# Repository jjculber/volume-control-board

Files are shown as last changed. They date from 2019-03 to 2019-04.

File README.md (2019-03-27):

# volume-control-board

Volume? Level?

The goal of this project is to make a small PCB for controlling volume with a rotary encoder and digital potentiometer.

- __Audio Input__: 3.5mm TRS jack
- __Digital Potentiometer__: AD5254 (4 circuits, 256 taps, 10k or 50k ohms)
- __Audio Output__: Shielded RJ45 for sending 4 channels to amplifier with cat6

[schematic](hardware/schematic.pdf)

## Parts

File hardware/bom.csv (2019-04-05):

Id | Designator | Package | Quantity | Designation | Supplier and ref | Note
1 | J2 | Jack_3.5mm_CUI_SJ-3523-SMT_Horizontal | 1 | AudioJack3 | CP-3523SJCT-ND
2 | REF**,REF**,REF**,REF** | MountingHole_2.2mm_M2 | 4 | MountingHole_2.2mm_M2
3 | C1,C2,C3,C4,C5 | C_0805 | 5 | 0.1uF
4 | J1 | Socket_Strip_Straight_1x08_Pitch2.54mm | 1 | Screw_Terminal_01x08 | A98333-ND (x4)
5 | J4,J5 | Socket_Strip_Straight_1x04_Pitch2.54mm | 2 | Conn_01x04 | A98333-ND (x2)
6 | J6 | Socket_Strip_Straight_1x02_Pitch2.54mm | 1 | RXTX/CAN | A98333-ND
7 | JP1,JP2,JP3,JP4,JP5,JP6,JP7,JP8,JP9,JP10,JP11,JP12 | SolderJumper-2_P1.3mm_Open_RoundedPad1.0x1.5mm | 12 | SolderJumper_2_Open
8 | R1,R2 | R_0805 | 2 | 2.2k
9 | R3,R4,R5,R6,R7,R8,R9 | R_0805 | 7 | 10k
10 | R10,R11,R12,R13 | R_0805 | 4 | R
11 | SW1 | RotaryEncoder_Alps_EC11E-Switch_Vertical_H20mm | 1 | Rotary_Encoder_Switch | 987-1188-ND
12 | U1 | Teensy30_31_32_LC | 1 | Teensy3.2 | 1568-1231-ND
13 | U2 | TSSOP-20_4.4x6.5mm_Pitch0.65mm | 1 | AD5254 | AD5254BRUZ10-RL7CT-ND
14 | J7,J3 | Grove_1x04 | 2 | Conn_01x04 | 455-1706-ND | 6 inch jumper cable: 455-3151-ND

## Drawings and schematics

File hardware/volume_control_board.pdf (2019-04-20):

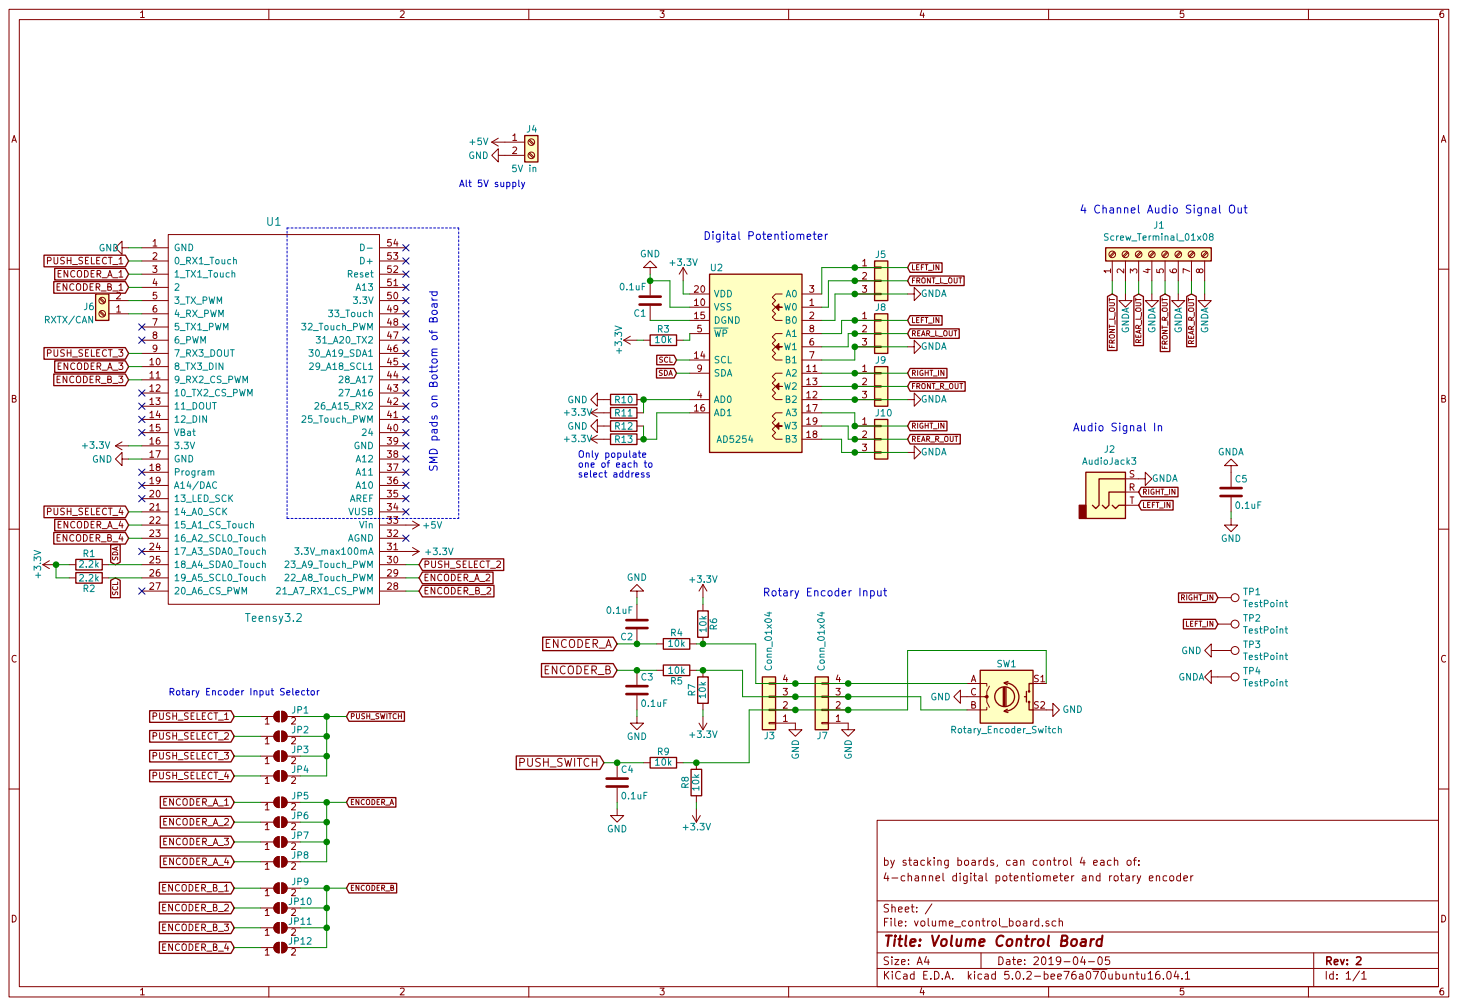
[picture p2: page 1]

SCL SDA

0.1uF GND Audio Signal In

one of each to

JP12 Rotary Encoder Input Selector

by stacking boards, can control 4 each of:
File: volume_control_board.sch Sheet: / 4-channel digital potentiometer and rotary encoder

Id: 1/1 Title: Volume Control Board

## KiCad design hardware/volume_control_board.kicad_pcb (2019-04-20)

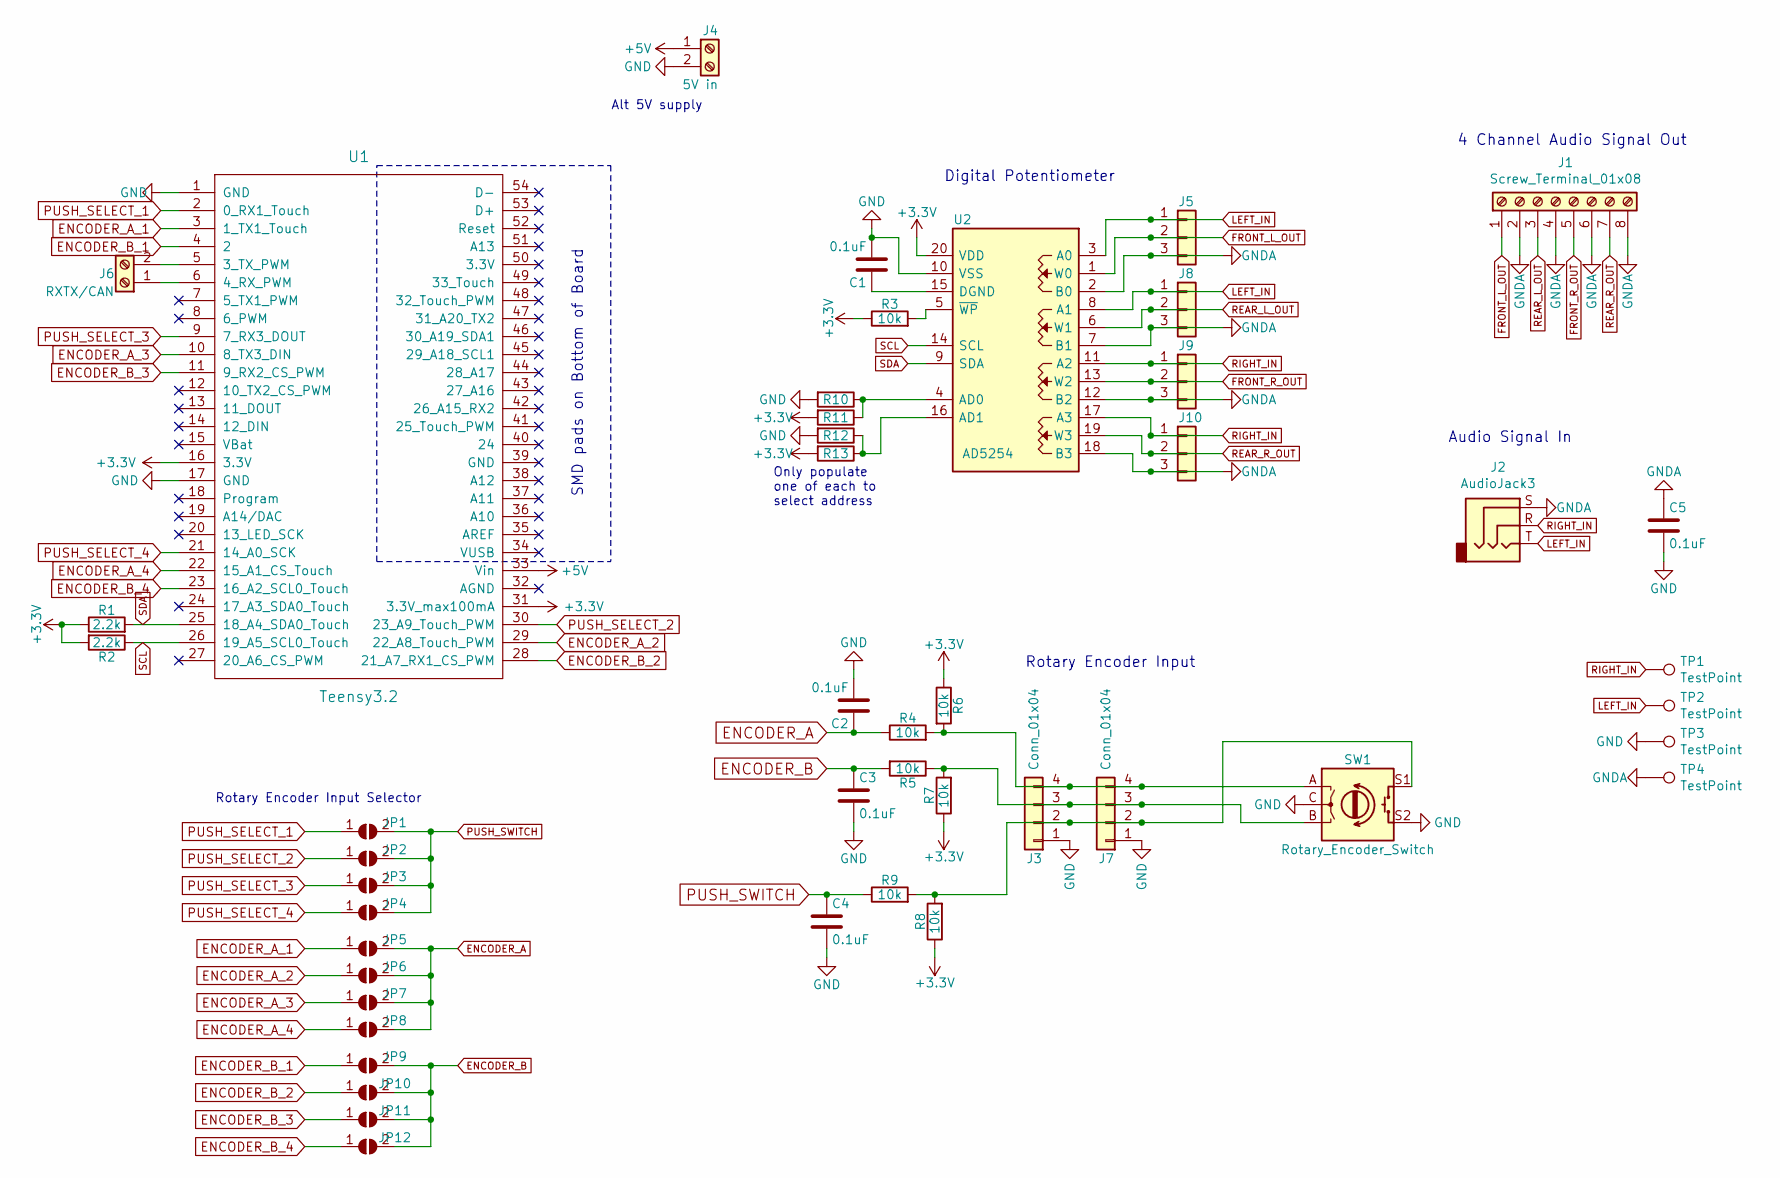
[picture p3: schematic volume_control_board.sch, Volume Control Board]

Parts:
C1, C2, C3, C4, C5: 0.1uF; C_0805
J1: Screw_Terminal_01x08; Socket_Strip_Straight_1x08_Pitch2.54mm
J2: AudioJack3; Jack_3.5mm_CUI_SJ-3523-SMT_Horizontal
J3, J7: Conn_01x04; Grove_1x04
J4: 5V in; Socket_Strip_Straight_1x02_Pitch2.54mm
J5, J8, J9, J10: Conn_01x03; Socket_Strip_Straight_1x03_Pitch2.00mm
J6: RXTX/CAN; Socket_Strip_Straight_1x02_Pitch2.54mm
JP1, JP2, JP3, JP4, JP5, JP6, JP7, JP8, JP9, JP10, JP11, JP12: SolderJumper_2_Open; SolderJumper-2_P1.3mm_Open_RoundedPad1.0x1.5mm
R1, R2: 2.2k; R_0805
R3, R4, R5, R6, R7, R8, R9: 10k; R_0805
R10, R11, R12, R13: R; R_0805
SW1: Rotary_Encoder_Switch; RotaryEncoder_Alps_EC11E-Switch_Vertical_H20mm
TP1, TP2, TP3, TP4: TestPoint; Measurement_Point_Round-TH_Small
U1: Teensy3.2; Teensy30_31_32_LC
U2: AD5254; TSSOP-20_4.4x6.5mm_Pitch0.65mm

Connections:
+3V3: R1.1, R2.2, R3.1, R6.1, R7.1, R8.1, R11.2, R13.2, U1.16 (3.3V), U1.31 (3.3V_max100mA), U2.20 (VDD)
+5V: J4.1, U1.33 (Vin)
ENCODER_A: C2.1, JP5.2 (B), JP6.2 (B), JP7.2 (B), JP8.2 (B), R4.1
ENCODER_A_1: JP5.1 (A), U1.3 (1_TX1_Touch)
ENCODER_A_2: JP6.1 (A), U1.29 (22_A8_Touch_PWM)
ENCODER_A_3: JP7.1 (A), U1.10 (8_TX3_DIN)
ENCODER_A_4: JP8.1 (A), U1.22 (15_A1_CS_Touch)
ENCODER_B: C3.1, JP9.2 (B), JP10.2 (B), JP11.2 (B), JP12.2 (B), R5.2
ENCODER_B_1: JP9.1 (A), U1.4 (2)
ENCODER_B_2: JP10.1 (A), U1.28 (21_A7_RX1_CS_PWM)
ENCODER_B_3: JP11.1 (A), U1.11 (9_RX2_CS_PWM)
ENCODER_B_4: JP12.1 (A), U1.23 (16_A2_SCL0_Touch)
FRONT_L_OUT: J1.1, J5.2, U2.1 (W0)
FRONT_R_OUT: J1.5, J9.2, U2.13 (W2)
GND: C1.2, C2.2, C3.2, C4.2, C5.2, J3.1, J4.2, J7.1, R10.2, R12.2, SW1.C, SW1.S2, TP3.1, U1.1 (GND), U1.17 (GND), U2.10 (VSS)
GNDA: C5.1, J1.2, J1.4, J1.6, J1.8, J2.S, J5.3, J8.3, J9.3, J10.3, TP4.1, U2.2 (B0), U2.7 (B1), U2.12 (B2), U2.18 (B3)
LEFT_IN: J2.T, J5.1, J8.1, TP2.1, U2.3 (A0), U2.8 (A1)
unnamed: C1.1, U2.15 (DGND)
unnamed: J3.2, J7.2, R8.2, R9.2, SW1.S1
unnamed: J3.3, J7.3, R5.1, R7.2, SW1.B
unnamed: J3.4, J7.4, R4.2, R6.2, SW1.A
unnamed: J6.1, U1.6 (4_RX_PWM)
unnamed: J6.2, U1.5 (3_TX_PWM)
unnamed: R3.2, U2.5 (~WP~)
unnamed: R10.1, R11.1, U2.4 (AD0)
unnamed: R12.1, R13.1, U2.16 (AD1)
PUSH_SELECT_1: JP1.1 (A), U1.2 (0_RX1_Touch)
PUSH_SELECT_2: JP2.1 (A), U1.30 (23_A9_Touch_PWM)
PUSH_SELECT_3: JP3.1 (A), U1.9 (7_RX3_DOUT)
PUSH_SELECT_4: JP4.1 (A), U1.21 (14_A0_SCK)
PUSH_SWITCH: C4.1, JP1.2 (B), JP2.2 (B), JP3.2 (B), JP4.2 (B), R9.1
REAR_L_OUT: J1.3, J8.2, U2.6 (W1)
REAR_R_OUT: J1.7, J10.2, U2.19 (W3)
RIGHT_IN: J2.R, J9.1, J10.1, TP1.1, U2.11 (A2), U2.17 (A3)
SCL: R2.1, U1.26 (19_A5_SCL0_Touch), U2.14 (SCL)
SDA: R1.2, U1.25 (18_A4_SDA0_Touch), U2.9 (SDA)

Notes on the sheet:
4 Channel Audio Signal Out
Digital Potentiometer
Audio Signal In
Rotary Encoder Input
SMD pads on Bottom of Board
Rotary Encoder Input Selector
Only populate one of each to select address
Alt 5V supply

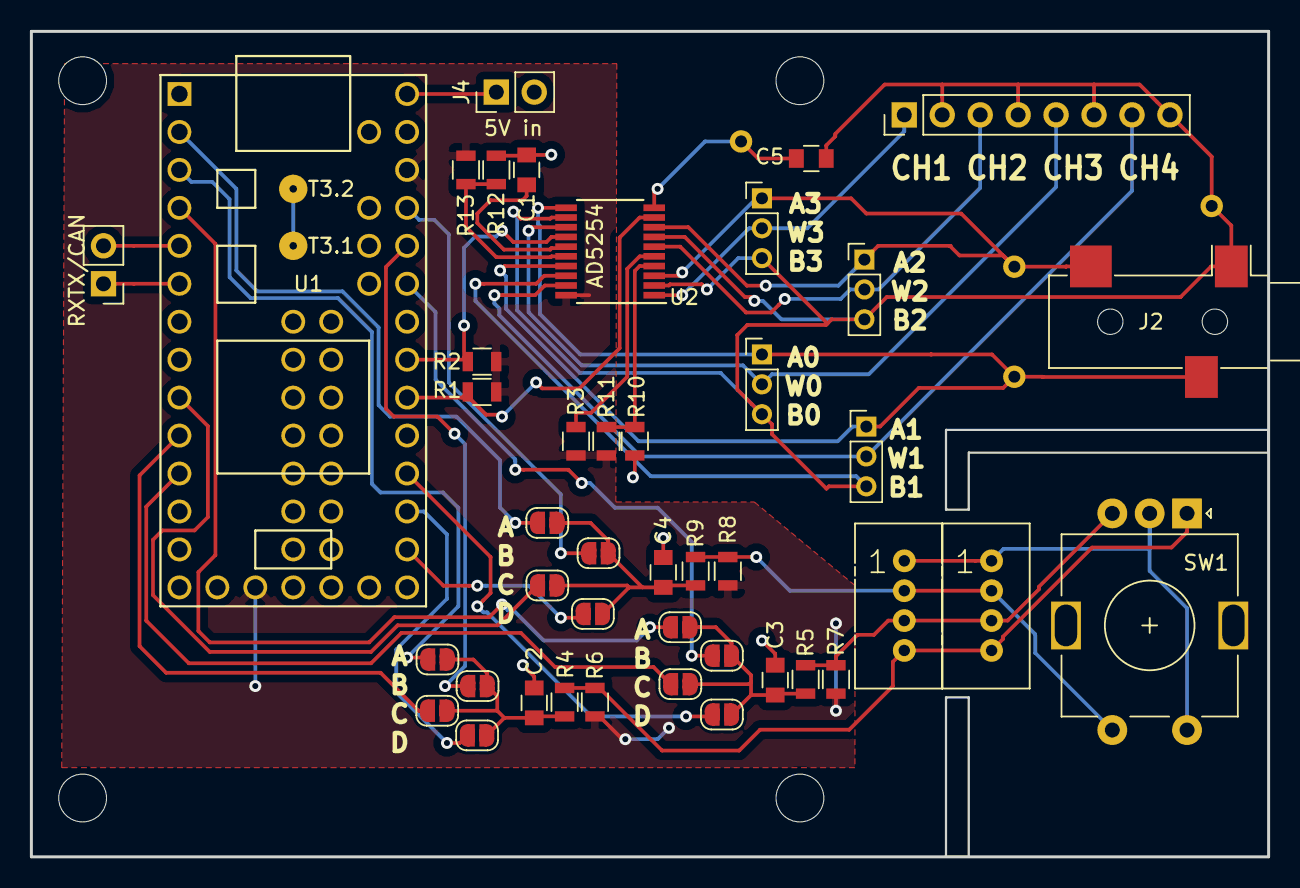
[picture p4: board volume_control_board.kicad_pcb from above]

Board: 2 copper layers, 82.8 x 55.2 mm, 47 parts (0 on the bottom side), 36 nets.

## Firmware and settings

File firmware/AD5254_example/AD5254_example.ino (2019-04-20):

// Distributed with a free-will license.
// Use it any way you want, profit or free, provided it fits in the licenses of its associated works.
// AD5254
// This code is designed to work with the AD5254_I2CPOT_10K I2C Mini Module available from ControlEverything.com.
// https://www.controleverything.com/content/Potentiometers?sku=AD5254_I2CPOT_10K#tabs-0-product_tabset-2

#include <Wire.h>
#include <Encoder.h>

// AD5254 I2C address is 0x2C(44)
#define Addr 0x2F

Encoder myEnc(1, 2);
const int buttonPin = 0;     // the number of the pushbutton pin
const int ledPin =  13;      // the number of the LED pin

void setup()
{
  
  // Initialise I2C communication as Master
  Wire.begin();
  
  // Initialise serial communication, set baud rate = 9600
  Serial.begin(9600);
  
  pinMode(buttonPin, INPUT);
  pinMode(ledPin, OUTPUT);

  mute();
  unmute();
}
unsigned int volume = 0;
unsigned int muted = 0;
long oldPosition  = -999;
int ledState = LOW;         // the current state of the output pin
int buttonState;             // the current reading from the input pin
int lastButtonState = LOW;   // the previous reading from the input pin
int registeredPress = 0;
long lastDebounceTime = 0;  // the last time the output pin was toggled
long debounceDelay = 50;    // the debounce time; increase if the output flickers

void loop()
{
  readPushButtonState();
  readRotaryEncoderState();
}

void readRotaryEncoderState() {
  long newPosition = myEnc.read();
  if (newPosition < 0) {
    Serial.print("<0 = ");
    Serial.println(newPosition);
    newPosition = 0;
    myEnc.write(0);
    readAndPrintAllValues();
  }
  if (newPosition > 255) {
    Serial.print(">255 = ");
    Serial.println(newPosition);
    newPosition = 255;
    myEnc.write(255);
    setAllValues(newPosition);
    readAndPrintAllValues();
  }
  if (newPosition != oldPosition) {
    //unmute();
    Serial.print("mid = ");
    Serial.println(newPosition);
    oldPosition = newPosition;
    setAllValues(newPosition);
    readAndPrintAllValues();
  }
}

void readPushButtonState() {
  // read the state of the switch into a local variable:
  int reading = digitalRead(buttonPin);

  // check to see if you just pressed the button 
  // (i.e. the input went from LOW to HIGH),  and you've waited 
  // long enough since the last press to ignore any noise:  

  // If the switch changed, due to noise or pressing:
  if (reading != lastButtonState) {
    // reset the debouncing timer
    lastDebounceTime = millis();
  } 
  
  if ((millis() - lastDebounceTime) > debounceDelay) {
    // whatever the reading is at, it's been there for longer
    // than the debounce delay, so take it as the actual current state:
    buttonState = reading;
    
    if (buttonState == LOW && registeredPress == 0) {
      ledState = ((ledState == LOW) ? HIGH : LOW);
      registeredPress = 1;
      // set the LED using the state of the button:
      if (ledState == HIGH) {
        mute();
      } else {
        unmute();
      }
    }
    if (buttonState == HIGH && registeredPress == 1) {
      registeredPress = 0;
    } 
  }
  // save the reading.  Next time through the loop,
  // it'll be the lastButtonState:
  lastButtonState = reading;
}

void mute() {
  ledState = HIGH;
  digitalWrite(ledPin, ledState);
  //setAllValues(0);

  Wire.beginTransmission(Addr);
  Wire.write(0x00);
  Wire.write(0x00);
  Wire.endTransmission();

  Wire.beginTransmission(Addr);
  Wire.write(0x01);
  Wire.write(0x00);
  Wire.endTransmission();

  Wire.beginTransmission(Addr);
  Wire.write(0x02);
  Wire.write(0x00);
  Wire.endTransmission();

  Wire.beginTransmission(Addr);
  Wire.write(0x03);
  Wire.write(0x00);
  Wire.endTransmission();
  
  Wire.beginTransmission(Addr);
  Wire.write(0x80);
  Wire.endTransmission();

  volume = 0;
  muted = 1;
  
  myEnc.write(0);
  Serial.println("muted");
  readAndPrintAllValues();
}

void unmute() {
  ledState = LOW;
  digitalWrite(ledPin, ledState);
  muted = 0;
  myEnc.write(1);
  setAllValues(1);
  Serial.println("unmuted");
  readAndPrintAllValues();
}

void readAndPrintAllValues() {
  unsigned int data = -1;

  // Start I2C transmission
  Wire.beginTransmission(Addr);
  // Select data register
  Wire.write(0x00);
  // Stop I2C transmission
  Wire.endTransmission();

  // Request 1 byte of data
  Wire.requestFrom(Addr, 1);

  // Read 1 byte of data
  if (Wire.available() == 1)
  {
    data = Wire.read();
  }
  // Convert the data
  float res_0 = (data / 256.0 ) * 10.0;

  // Start I2C transmission
  Wire.beginTransmission(Addr);
  // Select data register
  Wire.write(0x01);
  // Stop I2C transmission
  Wire.endTransmission();

  // Request 1 byte of data
  Wire.requestFrom(Addr, 1);

  // Read 1 byte of data
  if (Wire.available() == 1)
  {
    data = Wire.read();
  }
  // Convert the data
  float res_1 = (data / 256.0 ) * 10.0;

  // Start I2C transmission
  Wire.beginTransmission(Addr);
  // Select data register
  Wire.write(0x02);
  // Stop I2C transmission
  Wire.endTransmission();

  // Request 1 byte of data
  Wire.requestFrom(Addr, 1);

  // Read 1 byte of data
  if (Wire.available() == 1)
  {
    data = Wire.read();
  }
  // Convert the data
  float res_2 = (data / 256.0 ) * 10.0;

  // Start I2C transmission
  Wire.beginTransmission(Addr);
  // Select data register
  Wire.write(0x03);
  // Stop I2C transmission
  Wire.endTransmission();

  // Request 1 byte of data
  Wire.requestFrom(Addr, 1);

  // Read 1 byte of data
  if (Wire.available() == 1)
  {
    data = Wire.read();
  }
  // Convert the data
  float res_3 = (data / 256.0 ) * 10.0;

  // Output data to serial monitor
  Serial.print("Resistance Channel-0 : ");
  Serial.print(res_0);
  Serial.println(" K");
  Serial.print("Resistance Channel-1 : ");
  Serial.print(res_1);
  Serial.println(" K");
  Serial.print("Resistance Channel-2 : ");
  Serial.print(res_2);
  Serial.println(" K");
  Serial.print("Resistance Channel-3 : ");
  Serial.print(res_3);
  Serial.println(" K");
}

void setAllValues(unsigned int val) {
  if (muted == 1) {
    return;
  }
  uint8_t command = 0x80; // nop
  if (volume > val) {
    // decrease volume
    command = 0xb0;
  } else if (volume < val) {
    // increase volume
    command = 0xd8;
  }
  Serial.println(command);

  Wire.beginTransmission(Addr);
  Wire.write(command);
  Wire.endTransmission();
  
  Wire.beginTransmission(Addr);
  Wire.write(0x80);
  Wire.endTransmission();

  volume = val;
  return;


  // Start I2C transmission
  Wire.beginTransmission(Addr);
  // Send instruction for POT channel-0
  Wire.write(0x00);
  // Input resistance value, 0x80(128)
  //Wire.write(val);
  // Stop I2C transmission
  Wire.endTransmission();

  // Start I2C transmission
  Wire.beginTransmission(Addr);
  // Send instruction for POT channel-1
  Wire.write(0x01);
  // Input resistance value, 0x80(128)
  Wire.write(val);
  // Stop I2C transmission
  Wire.endTransmission();

  // Start I2C transmission
  Wire.beginTransmission(Addr);
  // Send instruction for POT channel-2
  Wire.write(0x02);
  // Input resistance value, 0x80(128)
  Wire.write(val);
  // Stop I2C transmission
  Wire.endTransmission();

  // Start I2C transmission
  Wire.beginTransmission(Addr);
  // Send instruction for POT channel-3
  Wire.write(0x03);
  // Input resistance value, 0x80(128)
  Wire.write(val);
  // Stop I2C transmission
  Wire.endTransmission();

}

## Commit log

2019-02-02 Initial schematic layout.
    [volume_control_board.kicad_pcb, volume_control_board.sch]
2019-03-27 Added CS for Rotary Encoder and cleaned up a bit.
    [volume_control_board-2019-03-13-15-03-11.sch]
2019-03-27 finished first draft.
    [volume_control_board.sch]
2019-04-05 firmware v1 and board v2
    [bom.csv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]
2019-04-06 added a few resistors for adjusting later.
    [volume_control_board-B.Cu.gbr, volume_control_board-B.Mask.gbr, volume_control_board-B.Paste.gbr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]
2019-04-20 updated board with more breakouts.
    [volume_control_board-B.Cu.gbr, volume_control_board-B.Mask.gbr, volume_control_board-B.Paste.gbr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]
2019-04-20 added silk pin descriptions.
    [volume_control_board-B.Cu.gbr, volume_control_board-B.Mask.gbr, volume_control_board-B.Paste.gbr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]
